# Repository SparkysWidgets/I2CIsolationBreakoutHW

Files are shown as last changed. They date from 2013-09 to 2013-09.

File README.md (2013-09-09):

Welcome To: I2C Isolation Breakout Hardware Repo!!
================================

##### Note: This is for the I2C Isolation Breakout Hardware Version 1 Branch

I2CisoBreakout Hardware Design Files in EAGLE. Not much to say, there are some custom parts will add Library after I clean it up!

Schematic Info
-------------------------
##### Basic schematic is split into sections

- Primary and Secondary sides for (both)
- ADUM6010 Isolated DC-DC converter with on chip transformers
- ADUM1251 I2C Isolation IC, bi-directional even on SCL
- Selectable voltage output (3.3 or 5v)
- Enable/Disable selector with tri state to allow external device to control

Board Layout Info
-------------------------
##### Form Factor based on Dangerous Prototypes SoB 50mmx50mm PCB size

- Standard 2.54mm pitch header and Grove style connector
- Power on bottom with isolation IC on top, Single supply
- Power IC can be switched on or off to all for isolation with separate supplies
- Selectable voltage output (3.3 or 5v)
- Enable/Disable selector with tri state to allow external device to control

Errata
-------------------------

##### Just a quick list of current issues
- Spacing between Primary and Isolation headers needs to be shrunk to better fit a bread board
- Clear silkscreen for power selection, and voltage selection on outputs

Firmware
-------------------------

- This is a "dumb" module and doesn't need any special firmware, In fact its a direct drop in series placement for I2C devices!!

Basic Usage
-------------------------

Usages of this device is very simple, it always for direct placement in series with an existing I2C Device, For those on the Grove style connector eco-system this breakout is extremely easy to use!

####Some of the commands are:
- Galvanic Isolation of I2C sensors
- Selectable Level shifter
- Allow for Hot/Swap or power down of I2C peripherals
- Power pullups (on host mainly) separately from VCC

License Info
-------------------------

<p>This is a fully open source project released under the CC BY license</p>
<br />
<span xmlns:dct="http://purl.org/dc/terms/" property="dct:title">I2C Isolation Breakout</span> by <a xmlns:cc="http://creativecommons.org/ns#" href="www.sparkyswidgets.com" property="cc:attributionName" rel="cc:attributionURL">Ryan Edwards, Sparky's Widgets</a> is licensed under a <a rel="license" href="http://creativecommons.org/licenses/by-sa/3.0/deed.en_US">Creative Commons Attribution-ShareAlike 3.0 Unported License</a>.<br />
Based on a work at <a xmlns:dct="http://purl.org/dc/terms/" href="/portfolio-item/i2c-isolation-breakout/" rel="dct:source">http://www.sparkyswidgets.com/portfolio-item/i2c-isolation-breakout/</a>

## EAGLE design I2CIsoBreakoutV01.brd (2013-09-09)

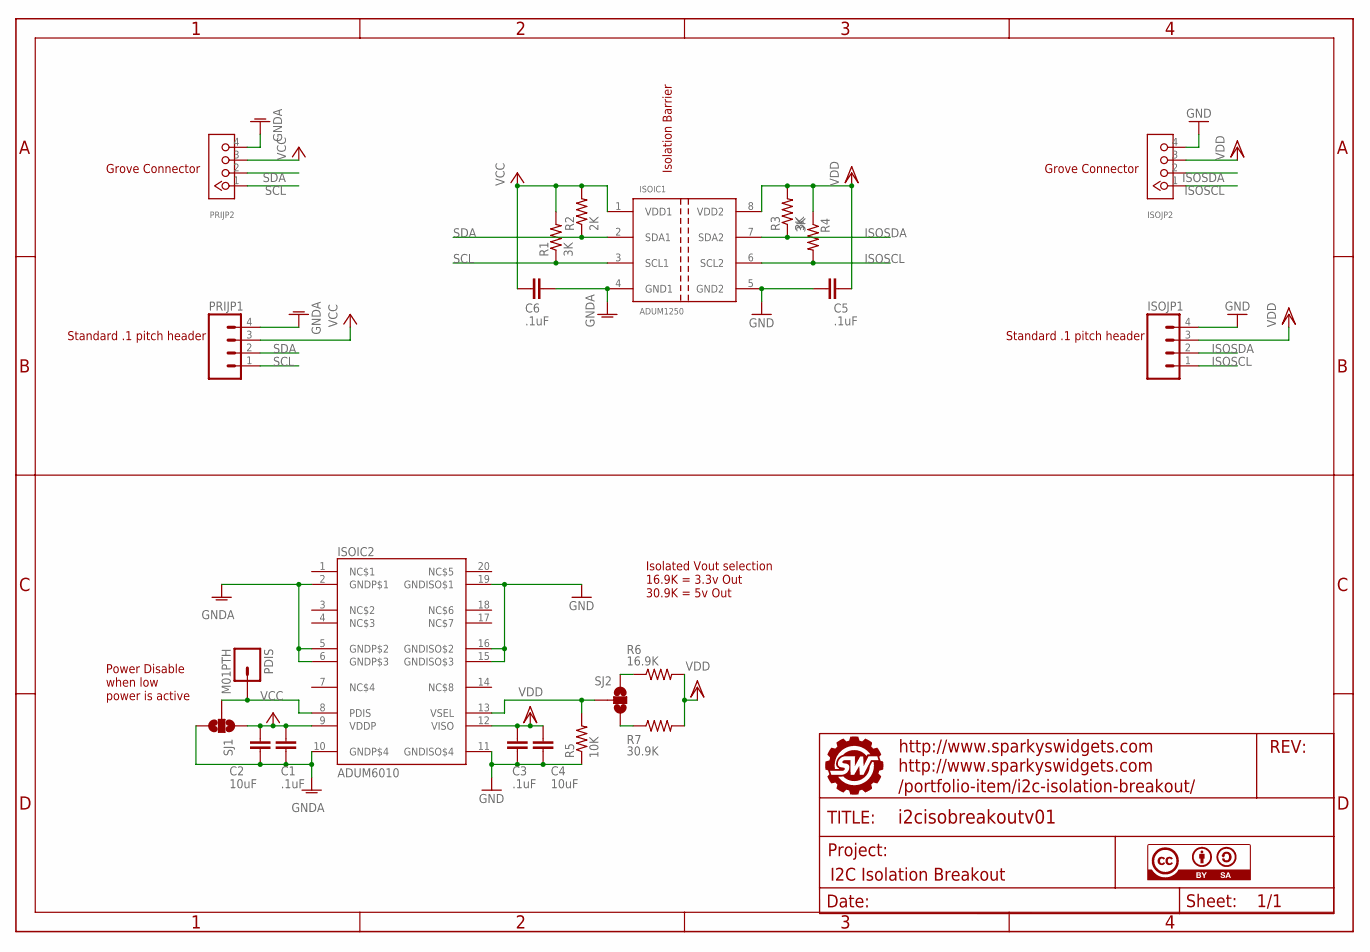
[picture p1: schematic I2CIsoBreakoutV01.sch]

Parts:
C1, C3, C5, C6: .1uF; 0805
C2, C4: 10uF; 0805
ISOIC1: ADUM1250; SO08
ISOIC2: ADUM6010; SSOP20
ISOJP1: M04PTH; 1X04
ISOJP2: TWIG-4P-2.0-2.0; 4P-2.0
PDIS: M01PTH; 1X01
PRIJP1: M04PTH; 1X04
PRIJP2: TWIG-4P-2.0-2.0; 4P-2.0
R1, R3, R4: 3K; 0805
R2: 2K; 0805
R5: 10K; 0805
R6: 16.9K; 0805
R7: 30.9K; 0805
SJ1, SJ2: SOLDERJUMPER_2WAYPASTE2&3; SJ_3_PASTE2&3
U$1: FRAME_ISOI2CBREAKOUT; SWPCBLOGOWITHINFO
U$2: CC-BY-SA

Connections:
GND: C3.2, C4.2, C5.1, ISOIC1.5 (GND2), ISOIC2.11 (GNDISO$4), ISOIC2.15 (GNDISO$3), ISOIC2.16 (GNDISO$2), ISOIC2.19 (GNDISO$1), ISOJP1.4, ISOJP2.4, R5.1
GNDA: C1.2, C2.2, C6.1, ISOIC1.4 (GND1), ISOIC2.2 (GNDP$1), ISOIC2.5 (GNDP$2), ISOIC2.6 (GNDP$3), ISOIC2.10 (GNDP$4), PRIJP1.4, PRIJP2.4, SJ1.3
ISOSCL: ISOIC1.6 (SCL2), ISOJP1.1, ISOJP2.1, R4.2
ISOSDA: ISOIC1.7 (SDA2), ISOJP1.2, ISOJP2.2, R3.1
unnamed: ISOIC2.8 (PDIS), PDIS.1, SJ1.2
unnamed: ISOIC2.13 (VSEL), R5.2, SJ2.2
unnamed: R6.1, SJ2.1
unnamed: R7.1, SJ2.3
SCL: ISOIC1.3 (SCL1), PRIJP1.1, PRIJP2.1, R1.1
SDA: ISOIC1.2 (SDA1), PRIJP1.2, PRIJP2.2, R2.1
VCC: C1.1, C2.1, C6.2, ISOIC1.1 (VDD1), ISOIC2.9 (VDDP), PRIJP1.3, PRIJP2.3, R1.2, R2.2, SJ1.1
VDD: C3.1, C4.1, C5.2, ISOIC1.8 (VDD2), ISOIC2.12 (VISO), ISOJP1.3, ISOJP2.3, R3.2, R4.1, R6.2, R7.2

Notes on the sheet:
Grove Connector
Standard .1 pitch header
Isolation Barrier
Power Disable when low power is active
Isolated Vout selection 16.9K = 3.3v Out 30.9K = 5v Out

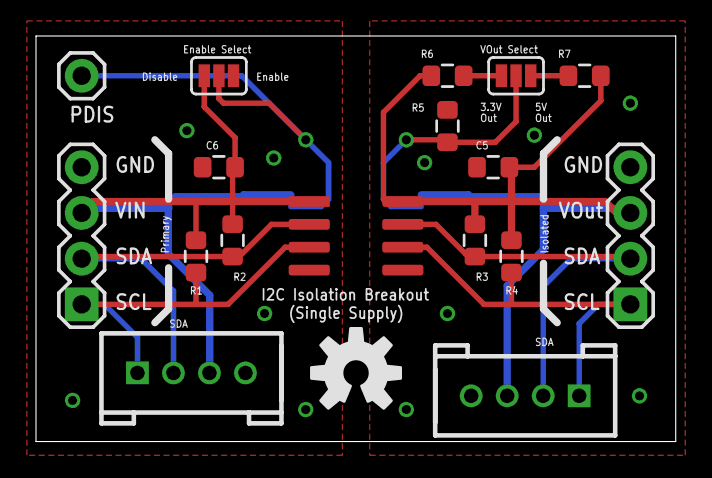
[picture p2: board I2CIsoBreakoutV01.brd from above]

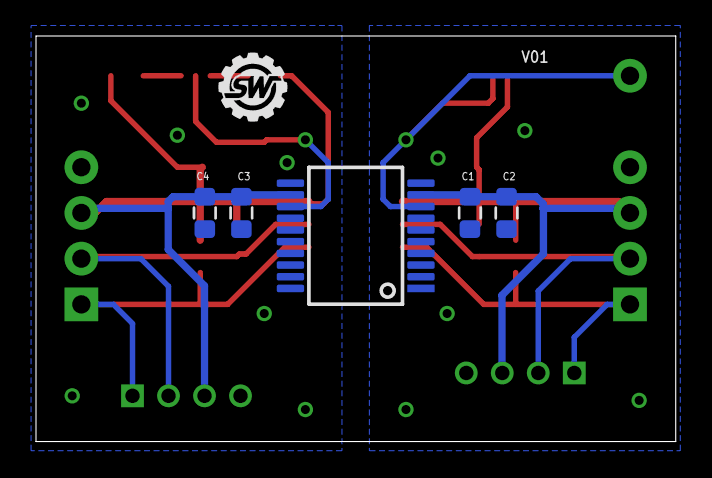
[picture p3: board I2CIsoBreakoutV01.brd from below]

Board: 2 copper layers, 35.5 x 22.5 mm, 25 parts (6 on the bottom side), 12 nets.

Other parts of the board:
U$3: OSHW-LOGO-M
